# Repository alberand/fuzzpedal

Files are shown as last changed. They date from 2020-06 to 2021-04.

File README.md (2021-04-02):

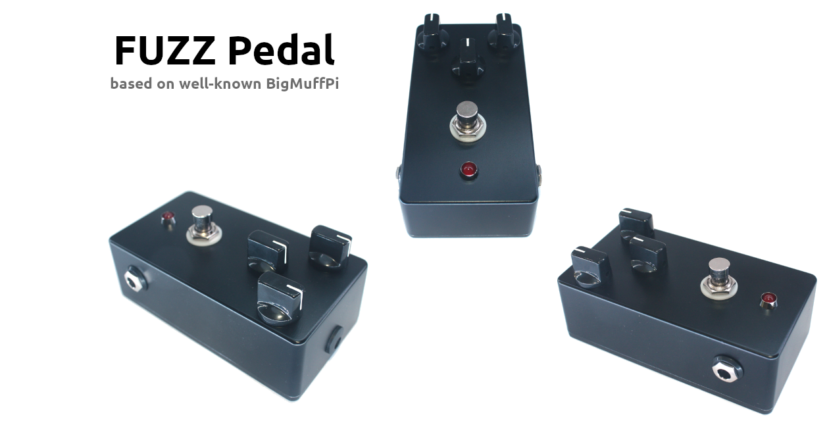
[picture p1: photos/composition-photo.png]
DIY Fuzz Pedal


This repository contains a lot of information on how to build a Fuzz Pedal based
on well-known Big Muff PI pedal.

## Demo Reconds

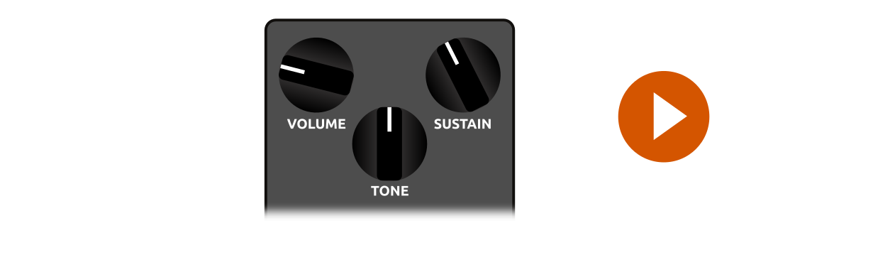
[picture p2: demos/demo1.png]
Demo 1
[][4] 

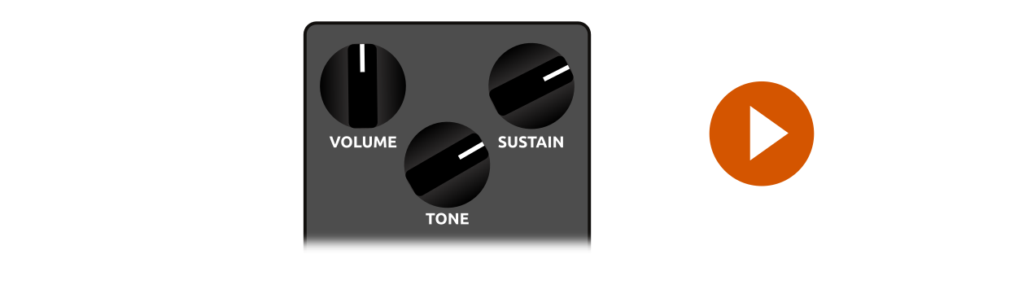
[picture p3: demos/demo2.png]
Demo 2
[][5] 

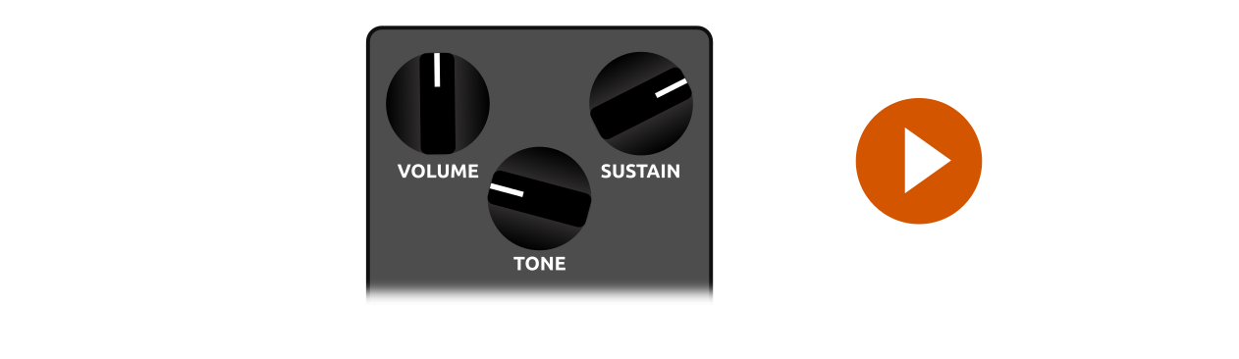
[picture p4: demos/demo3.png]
Demo 3
[][6] 

### Schematics

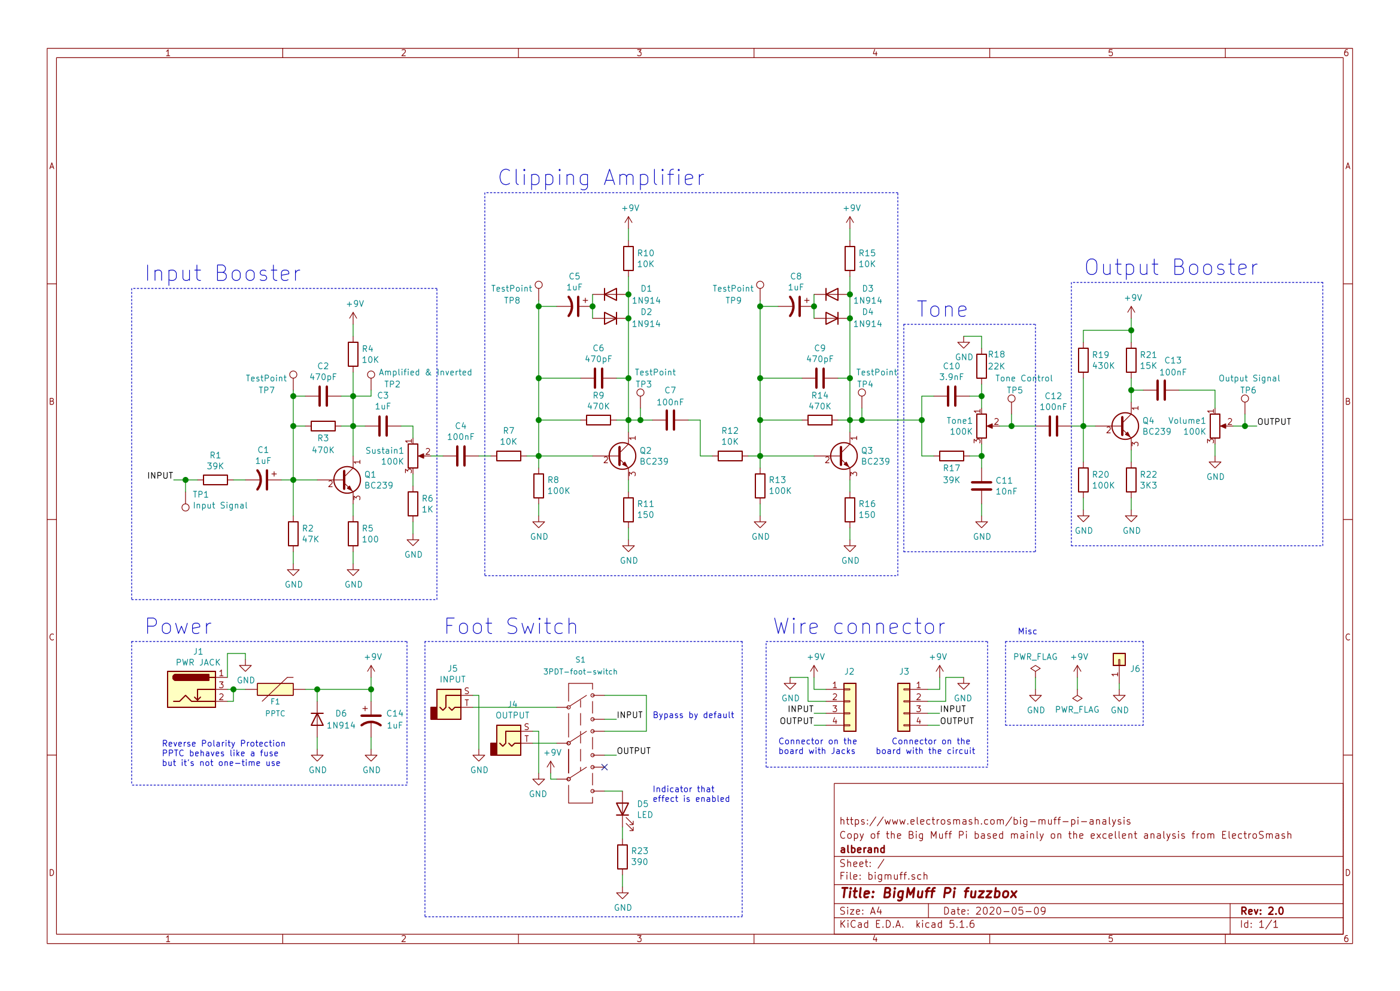
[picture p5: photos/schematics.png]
Fuzz Pedal schematics


### PCB dimensions

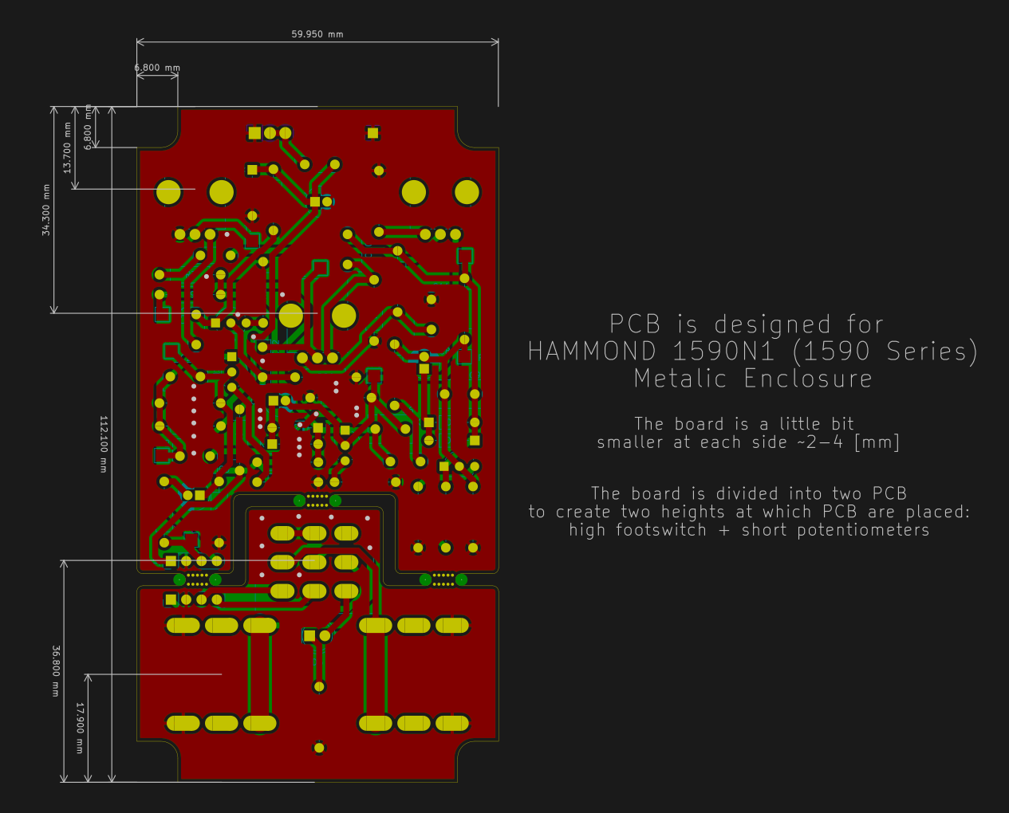
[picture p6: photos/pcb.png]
Fuzz Pedal PCB


### 3D Render of PCB

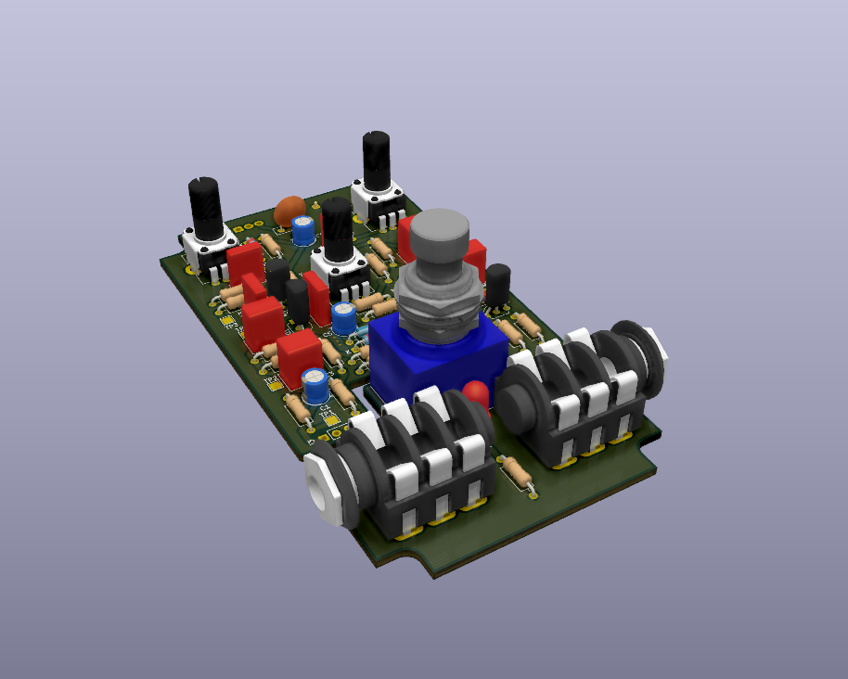
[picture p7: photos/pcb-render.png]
Fuzz Pedal render


### Photo of PCB

Photo of Fuzz Pedal PCB

### Photo of assembled pedal

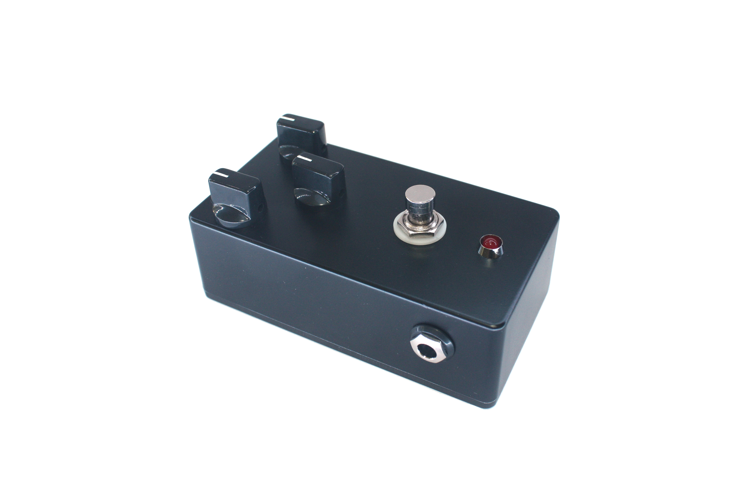
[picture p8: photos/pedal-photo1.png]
Photo of assembled Fuzz Pedal


## TODO

* Add [rubber feets][1] (After discussion seems to be unnecessary and it's better to have Hook-and-loop fastener)
* Write article on how to paint Aluminum case
* Add template for drilling holes (A4 paper with holes)
* Update BOM (better caps, better LED holder)  - in progress
* Try screen print on the case
* Describe screen printing process
* Find what to use as a final coat for case painting

## Cost

Here is crude cost calculation of one Pedal. Remember that this doesn't include
any tools. The shipping price could vary (in my case I had many more parcels
😕). In total one pedal cost about 50 - 60 💶 euro (without shipping) + you would
have a few paint sprays.

| Material Type | Quantity | Price [EUR] |
|---|---|---|
| PCB | 5 (min amount) | 8.5 |
| Electronic components & Misc | 1 set | 25 |
| Case | 1 | 11 |
| Ground & Color & Clear Paint | 3 | 6x3 |
| Shipping | ~4 | 20x4 |

How long does it take to make a pedal? If you have any experience in soldering,
painting it will take somewhere around 33 hours mainly due waiting for paint to
dry.

| Activity Type | Time [hours] |
|---|---|
| Board Soldering | 5 |
| Case drilling | 2 |
| Case cleaning & polishing | 0.5 |
| Case painting | 25 |
| Assembling | 0.5 |

## Assembling process

TODO In progress

The assebmly process is quite simple. The most time-consuming part is PCB
soldering. Otherwise, you just need to put PCB into box.

### Order components & PCB

1. Import BOM to Mouser or Farnell and order components. The BOM is prepared for
   those to distributors. However, sometimes components aren't in stock and it
   can take months for them to restock them.
2. Order the rest of the components from Aliexpress - enclosure and foot switch.
   Those parts are also available on Amazon. I would recommend to by foot switch
   from amazon as it seems to be in better quality. The case could be also
   ordered from Mouser or Farnell.
3. Import Gerber files to PCB manufacturer and order PCBs. I used jlcpcb.com
   which worked out quite well.

### Solder board

1. TODO image of the component placement (print it)
2. I recommend soldering components in the following order:
    1. Resistors
    2. Electrolytic Capacitors (those with polarity)
    3. Capacitor
    4. Transistors
    5. Diodes
    6. Thermal fuse (yellow)
    7. Potentiometers, Jacks and Switch
    8. Wires between PCBs
3. Prepare wires, LED with wires and power jack with wires
4. Solder wires to LED and to the Power jack, but don't solder it to the board
   yet. Also, don't forget to put heat shrink tubes.
5. Solder the LED to the board 

### Enclosure processing

TODO describe what instruments to use
1. Print the template for the hole placement (TODO not in the repo)
2. Cut the template and attach it to the case with adhesive tape
3. Drill the holes
4. Remove the template and polish the case with different sandpapers (TODO add
   sizes)
5. Paint the case (read the instruction on the spray):
    1. 2 layers of primer
    2. 2 layers of color paint
    3. 1 layers of protection layer
6. Screen printing (TODO)

### Assemble the pedal

1. Break the board
2. Put the LED into the case and screw it to the case
3. Screw switch and jacks
4. Put second board into the enclosure and screw the knobs
5. Put power jack into the enclosure
6. Solder power jack wires to the board
7. Use thermal glue (TODO it doesn't work) to fix the board inside the case
8. Screw the bottom of the enclosure

### References

* [ElectroSmash - Big Muff PI analysis](https://www.electrosmash.com/big-muff-pi-analysis)
* [How to "Screen printing"](https://www.youtube.com/watch?v=NS8Q9LUIKA8)

[1]: http://www.diyguitarpedals.com.au/shop/index.php?main_page=product_info&cPath=15&products_id=591
[2]: http://www.caravanelectroworks.com/?p=418
[3]: http://rezzonics.blogspot.com/2018/05/nutube-screamer-schematics-bom-layout.html
[4]: https://soundcloud.com/user-605705068/fuzzpedal-demo-param-1
[5]: https://soundcloud.com/user-605705068/fuzzpedal-demo-param-2
[6]: https://soundcloud.com/user-605705068/fuzzpedal-demo-param-3

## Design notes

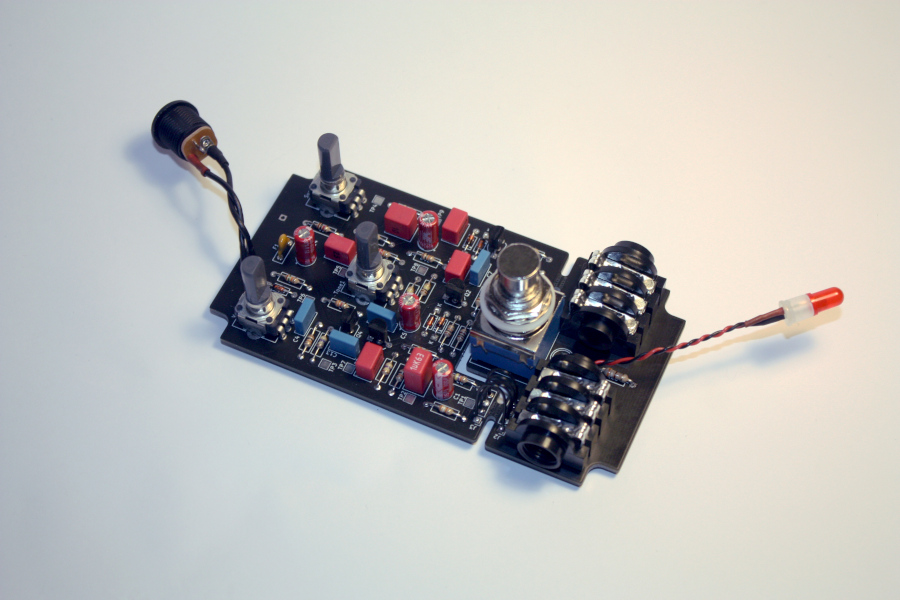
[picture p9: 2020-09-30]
photos/pcb-photo.jpg

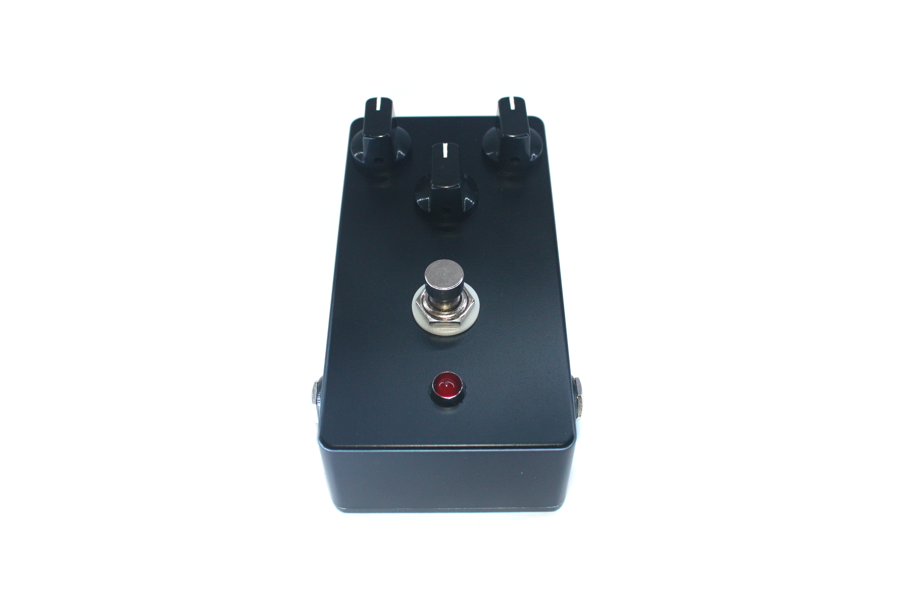
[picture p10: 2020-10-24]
photos/pedal-photo2.png

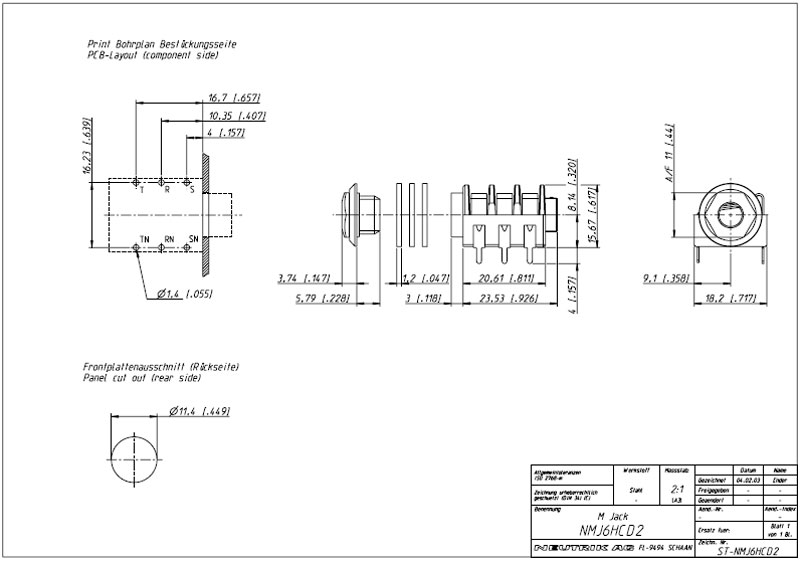
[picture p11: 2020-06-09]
datasheets/nmj6-size.jpg

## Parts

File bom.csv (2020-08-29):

Reference | Value | Footprint | Datasheet | Mfr. No | Mouser | Supplier | LCSC | Aliexpress | Comment | Field4
R1 | 39K | Resistor_THT:R_Axial_DIN0207_L6.3mm_D2.5mm_P10.16mm_Horizontal | https://cz.mouser.com/datasheet/2/447/yageo_yagos02873-1-1745585.pdf | CFR-12JB-52-39K | 603-CFR-12JB-52-39K | Mouser
C1 | 1uF | Capacitor_THT:CP_Radial_D5.0mm_P2.00mm | https://cz.mouser.com/datasheet/2/445/860020672005-1725471.pdf | 860020672005 | 710-860020672005 | Mouser
Q1 | BC239 | Package_TO_SOT_THT:TO-92L_Inline_Wide | https://cz.mouser.com/datasheet/2/308/BC550-D-1802078.pdf | BC549CTA | 512-BC549CTA | Mouser
R5 | 100 | Resistor_THT:R_Axial_DIN0207_L6.3mm_D2.5mm_P10.16mm_Horizontal | https://cz.mouser.com/datasheet/2/447/yageo_yagos02873-1-1745585.pdf | CFR-12JT-52-100R | 603-CFR-12JT-52-100R | Mouser
R2 | 47K | Resistor_THT:R_Axial_DIN0207_L6.3mm_D2.5mm_P10.16mm_Horizontal | https://cz.mouser.com/datasheet/2/447/yageo_yagos02873-1-1745585.pdf | CFR-12JB-52-47K | 603-CFR-12JB-52-47K | Mouser
R3 | 470K | Resistor_THT:R_Axial_DIN0207_L6.3mm_D2.5mm_P10.16mm_Horizontal | https://cz.mouser.com/datasheet/2/447/yageo_yagos02873-1-1745585.pdf | CFR-12JT-52-470K | 603-CFR-12JT-52-470K | Mouser
C2 | 470pF | Capacitor_THT:C_Rect_L7.2mm_W4.5mm_P5.00mm_FKS2_FKP2_MKS2_MKP2 | https://cz.mouser.com/datasheet/2/440/e_WIMA_FKP_2-1139852.pdf | FKP2D004701D00KSSD | 505-FKP2D004701DKSSD | Mouser
C3 | 1uF | Capacitor_THT:C_Rect_L7.2mm_W5.5mm_P5.00mm_FKS2_FKP2_MKS2_MKP2 | https://cz.mouser.com/datasheet/2/440/e_WIMA_MKS_2-1139871.pdf | MKS2C041001F00KI00 | 505-MKS2C041001FKI00 | Mouser
R4 | 10K | Resistor_THT:R_Axial_DIN0207_L6.3mm_D2.5mm_P10.16mm_Horizontal | https://cz.mouser.com/datasheet/2/447/yageo_yagos02873-1-1745585.pdf | CFR-12JT-52-10K | 603-CFR-12JT-52-10K | Mouser
R6 | 1K | Resistor_THT:R_Axial_DIN0207_L6.3mm_D2.5mm_P10.16mm_Horizontal | https://cz.mouser.com/datasheet/2/447/yageo_yagos02873-1-1745585.pdf | CFR-12JT-52-1K | 603-CFR-12JT-52-1K | Mouser
C4 | 100nF | Capacitor_THT:C_Rect_L7.2mm_W2.5mm_P5.00mm_FKS2_FKP2_MKS2_MKP2 | https://www.tdk-electronics.tdk.com/inf/20/20/db/fc_2009/B32520_529.pdf | B32529C104K000 | 871-B32529C104K000 | Mouser
R7 | 10K | Resistor_THT:R_Axial_DIN0207_L6.3mm_D2.5mm_P10.16mm_Horizontal | https://cz.mouser.com/datasheet/2/447/yageo_yagos02873-1-1745585.pdf | CFR-12JT-52-10K | 603-CFR-12JT-52-10K | Mouser
Q2 | BC239 | Package_TO_SOT_THT:TO-92L_Inline_Wide | https://cz.mouser.com/datasheet/2/308/BC550-D-1802078.pdf | BC549CTA | 512-BC549CTA | Mouser
R8 | 100K | Resistor_THT:R_Axial_DIN0207_L6.3mm_D2.5mm_P10.16mm_Horizontal | https://cz.mouser.com/datasheet/2/447/yageo_yagos02873-1-1745585.pdf | CFR-12JR-52-100K | 603-CFR-12JR-52-100K | Mouser
R9 | 470K | Resistor_THT:R_Axial_DIN0207_L6.3mm_D2.5mm_P10.16mm_Horizontal | https://cz.mouser.com/datasheet/2/447/yageo_yagos02873-1-1745585.pdf | CFR-12JT-52-470K | 603-CFR-12JT-52-470K | Mouser
C6 | 470pF | Capacitor_THT:C_Rect_L7.2mm_W4.5mm_P5.00mm_FKS2_FKP2_MKS2_MKP2 | https://cz.mouser.com/datasheet/2/440/e_WIMA_FKP_2-1139852.pdf | FKP2D004701D00KSSD | 505-FKP2D004701DKSSD | Mouser
C5 | 1uF | Capacitor_THT:CP_Radial_D5.0mm_P2.00mm | https://cz.mouser.com/datasheet/2/445/860020672005-1725471.pdf | 860020672005 | 710-860020672005 | Mouser
D1 | 1N914 | Diode_THT:D_DO-35_SOD27_P7.62mm_Horizontal | https://cz.mouser.com/datasheet/2/308/1N914-D-1801484.pdf | 1N914 | 512-1N914 | Mouser | C125665
D2 | 1N914 | Diode_THT:D_DO-35_SOD27_P7.62mm_Horizontal | https://cz.mouser.com/datasheet/2/308/1N914-D-1801484.pdf | 1N914 | 512-1N914 | Mouser | C125665
R10 | 10K | Resistor_THT:R_Axial_DIN0207_L6.3mm_D2.5mm_P10.16mm_Horizontal | https://cz.mouser.com/datasheet/2/447/yageo_yagos02873-1-1745585.pdf | CFR-12JT-52-10K | 603-CFR-12JT-52-10K | Mouser
R11 | 150 | Resistor_THT:R_Axial_DIN0207_L6.3mm_D2.5mm_P10.16mm_Horizontal | https://cz.mouser.com/datasheet/2/447/yageo_yagos02873-1-1745585.pdf | CFR-12JT-52-150R | 603-CFR-12JT-52-150R | Mouser
C7 | 100nF | Capacitor_THT:C_Rect_L7.2mm_W2.5mm_P5.00mm_FKS2_FKP2_MKS2_MKP2 | https://www.tdk-electronics.tdk.com/inf/20/20/db/fc_2009/B32520_529.pdf | B32529C104K000 | 871-B32529C104K000 | Mouser
R12 | 10K | Resistor_THT:R_Axial_DIN0207_L6.3mm_D2.5mm_P10.16mm_Horizontal | https://cz.mouser.com/datasheet/2/447/yageo_yagos02873-1-1745585.pdf | CFR-12JT-52-10K | 603-CFR-12JT-52-10K | Mouser
R13 | 100K | Resistor_THT:R_Axial_DIN0207_L6.3mm_D2.5mm_P10.16mm_Horizontal | https://cz.mouser.com/datasheet/2/447/yageo_yagos02873-1-1745585.pdf | CFR-12JR-52-100K | 603-CFR-12JR-52-100K | Mouser
R14 | 470K | Resistor_THT:R_Axial_DIN0207_L6.3mm_D2.5mm_P10.16mm_Horizontal | https://cz.mouser.com/datasheet/2/447/yageo_yagos02873-1-1745585.pdf | CFR-12JT-52-470K | 603-CFR-12JT-52-470K | Mouser
C9 | 470pF | Capacitor_THT:C_Rect_L7.2mm_W4.5mm_P5.00mm_FKS2_FKP2_MKS2_MKP2 | https://cz.mouser.com/datasheet/2/440/e_WIMA_FKP_2-1139852.pdf | FKP2D004701D00KSSD | 505-FKP2D004701DKSSD | Mouser
C8 | 1uF | Capacitor_THT:CP_Radial_D5.0mm_P2.00mm | https://cz.mouser.com/datasheet/2/445/860020672005-1725471.pdf | 860020672005 | 710-860020672005 | Mouser
D3 | 1N914 | Diode_THT:D_DO-35_SOD27_P7.62mm_Horizontal | https://cz.mouser.com/datasheet/2/308/1N914-D-1801484.pdf | 1N914 | 512-1N914 | Mouser | C125665
D4 | 1N914 | Diode_THT:D_DO-35_SOD27_P7.62mm_Horizontal | https://cz.mouser.com/datasheet/2/308/1N914-D-1801484.pdf | 1N914 | 512-1N914 | Mouser | C125665
R15 | 10K | Resistor_THT:R_Axial_DIN0207_L6.3mm_D2.5mm_P10.16mm_Horizontal | https://cz.mouser.com/datasheet/2/447/yageo_yagos02873-1-1745585.pdf | CFR-12JT-52-10K | 603-CFR-12JT-52-10K | Mouser
R16 | 150 | Resistor_THT:R_Axial_DIN0207_L6.3mm_D2.5mm_P10.16mm_Horizontal | https://cz.mouser.com/datasheet/2/447/yageo_yagos02873-1-1745585.pdf | CFR-12JT-52-150R | 603-CFR-12JT-52-150R | Mouser
Tone1 | 100K | Potentiometer_THT:Potentiometer_Alps_RK09K_Single_Vertical | https://cz.mouser.com/datasheet/2/15/RK09K-771158.pdf | RK09D113BF25B15 | 688-RK09D113BF25B15 | Mouser
C10 | 3.9nF | Capacitor_THT:C_Rect_L7.2mm_W4.5mm_P5.00mm_FKS2_FKP2_MKS2_MKP2 | https://cz.mouser.com/datasheet/2/440/e_WIMA_FKP_2-1139852.pdf | FKP2C013901D00HC00 | 505-FKP2C013901DHC00 | Mouser
R17 | 39K | Resistor_THT:R_Axial_DIN0207_L6.3mm_D2.5mm_P10.16mm_Horizontal | https://cz.mouser.com/datasheet/2/447/yageo_yagos02873-1-1745585.pdf | CFR-12JB-52-39K | 603-CFR-12JB-52-39K | Mouser
R18 | 22K | Resistor_THT:R_Axial_DIN0207_L6.3mm_D2.5mm_P10.16mm_Horizontal | https://cz.mouser.com/datasheet/2/447/yageo_yagos02873-1-1745585.pdf | CFR-12JT-52-22K | 603-CFR-12JT-52-22K | Mouser
C12 | 100nF | Capacitor_THT:C_Rect_L7.2mm_W2.5mm_P5.00mm_FKS2_FKP2_MKS2_MKP2 | https://www.tdk-electronics.tdk.com/inf/20/20/db/fc_2009/B32520_529.pdf | B32529C104K000 | 871-B32529C104K000 | Mouser
Q4 | BC239 | Package_TO_SOT_THT:TO-92L_Inline_Wide | https://cz.mouser.com/datasheet/2/308/BC550-D-1802078.pdf | BC549CTA | 512-BC549CTA | Mouser
R21 | 15K | Resistor_THT:R_Axial_DIN0207_L6.3mm_D2.5mm_P10.16mm_Horizontal | https://cz.mouser.com/datasheet/2/447/yageo_yagos02873-1-1745585.pdf | CFR-12JT-52-15K | 603-CFR-12JT-52-15K | Mouser
R19 | 430K | Resistor_THT:R_Axial_DIN0207_L6.3mm_D2.5mm_P10.16mm_Horizontal | https://cz.mouser.com/datasheet/2/447/yageo_yagos02873-1-1745585.pdf | CFR-12JB-52-430K | 603-CFR-12JB-52-430K | Mouser
C13 | 100nF | Capacitor_THT:C_Rect_L7.2mm_W2.5mm_P5.00mm_FKS2_FKP2_MKS2_MKP2 | https://www.tdk-electronics.tdk.com/inf/20/20/db/fc_2009/B32520_529.pdf | B32529C104K000 | 871-B32529C104K000 | Mouser
Volume1 | 100K | Potentiometer_THT:Potentiometer_Alps_RK09K_Single_Vertical | https://cz.mouser.com/datasheet/2/15/RK09K-771158.pdf | RK09D113BF25B15 | 688-RK09D113BF25B15 | Mouser
Sustain1 | 100K | Potentiometer_THT:Potentiometer_Alps_RK09K_Single_Vertical | https://cz.mouser.com/datasheet/2/15/RK09K-771158.pdf | RK09D113BF25B15 | 688-RK09D113BF25B15 | Mouser
R20 | 100K | Resistor_THT:R_Axial_DIN0207_L6.3mm_D2.5mm_P10.16mm_Horizontal | https://cz.mouser.com/datasheet/2/447/yageo_yagos02873-1-1745585.pdf | CFR-12JR-52-100K | 603-CFR-12JR-52-100K | Mouser
R22 | 3K3 | Resistor_THT:R_Axial_DIN0207_L6.3mm_D2.5mm_P10.16mm_Horizontal | https://cz.mouser.com/datasheet/2/447/yageo_yagos02873-1-1745585.pdf | CFR-12JR-52-3K3 | 603-CFR-12JR-52-3K3 | Mouser
C11 | 10nF | Capacitor_THT:C_Rect_L7.2mm_W5.5mm_P5.00mm_FKS2_FKP2_MKS2_MKP2 | https://cz.mouser.com/datasheet/2/440/e_WIMA_FKP_2-1139852.pdf | FKP2C021001G00KSSD | 505-FKP2C021001G00KS | Mouser
Q3 | BC239 | Package_TO_SOT_THT:TO-92L_Inline_Wide | https://cz.mouser.com/datasheet/2/308/BC550-D-1802078.pdf | BC549CTA | 512-BC549CTA | Mouser
S1 | 3PDT-foot-switch | bigmuffpi:SF17020F-0302-21R-L | https://cz.mouser.com/datasheet/2/13/SF17_SF12030F-1155740.pdf | 3PDT 9-Pin | 107-SF17020F-32-21RL | Aliexpress |  | https://www.aliexpress.com/item/1761081145.html?spm=a2g0o.cart.0.0.9a9e3c00NMRYVw&mp=1 | Much much cheaper from Aliexpress (look for 3PDT) | SWCH-10554
J1 | PWR JACK | Connector_PinHeader_2.54mm:PinHeader_1x03_P2.54mm_Vertical | https://www.aliexpress.com/wholesale?catId=0&SearchText=panel+mount+barrel+jack |  |  | Aliexpress
D6 | 1N914 | Diode_THT:D_DO-35_SOD27_P7.62mm_Horizontal | https://cz.mouser.com/datasheet/2/308/1N914-D-1801484.pdf | 1N914 | 512-1N914 | Mouser | C125665
J5 | INPUT | bigmuffpi:NMJ6HC-S | https://www.neutrik.us/en-us/product/nmj4hc-s.pdf | NMJ4HC-S | 568-NMJ4HC-S | Mouser
J4 | OUTPUT | bigmuffpi:NMJ6HC-S | https://www.neutrik.us/en-us/product/nmj4hc-s.pdf | NMJ4HC-S | 568-NMJ4HC-S | Mouser
R23 | 390 | Resistor_THT:R_Axial_DIN0207_L6.3mm_D2.5mm_P10.16mm_Horizontal | https://cz.mouser.com/datasheet/2/447/yageo_yagos02873-1-1745585.pdf | CFR-12JB-52-390R | 603-CFR-12JB-52-390R | Mouser
D5 | LED | LED_THT:LED_D5.0mm | https://cz.mouser.com/datasheet/2/427/tlhg540-1766965.pdf | TLHR5400-AS12Z | 78-TLHR5400-AS12Z | Mouser | C162069
F1 | PPTC | Capacitor_THT:C_Disc_D8.0mm_W2.5mm_P5.00mm | https://cz.mouser.com/datasheet/2/54/mfr-777680.pdf | MF-R020 | 652-MF-R020 | Mouser |  |  |  | RES-08585
C14 | 1uF | Capacitor_THT:CP_Radial_D5.0mm_P2.00mm | https://cz.mouser.com/datasheet/2/445/860020672005-1725471.pdf | 860020672005 | 710-860020672005 | Mouser

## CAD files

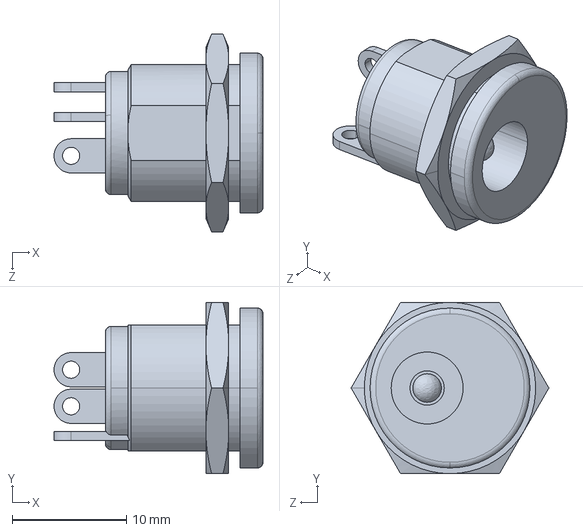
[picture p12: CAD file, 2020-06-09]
fuzzpedal/3dmodels/KLS1-DC-022B.step
18.3 x 15.0 x 17.3 mm

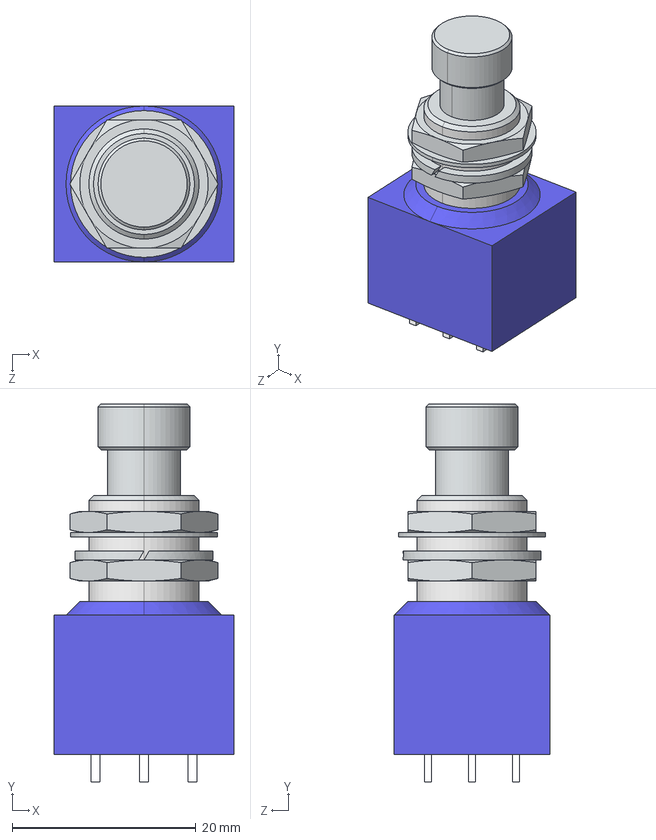
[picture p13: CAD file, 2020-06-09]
fuzzpedal/3dmodels/Footswich_3PDT.step
19.6 x 41.2 x 17.0 mm

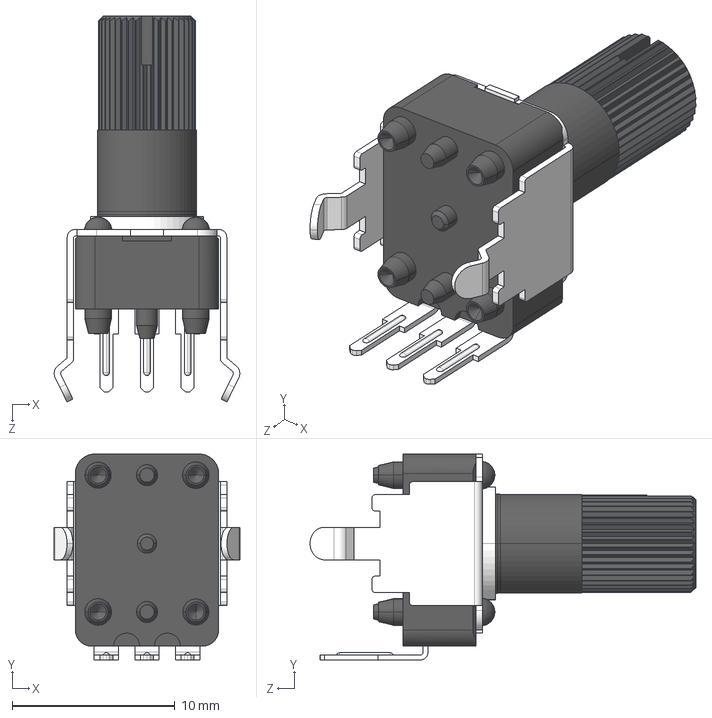
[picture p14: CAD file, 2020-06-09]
fuzzpedal/3dmodels/RK09K1130-20-1.step
11.4 x 12.7 x 23.7 mm

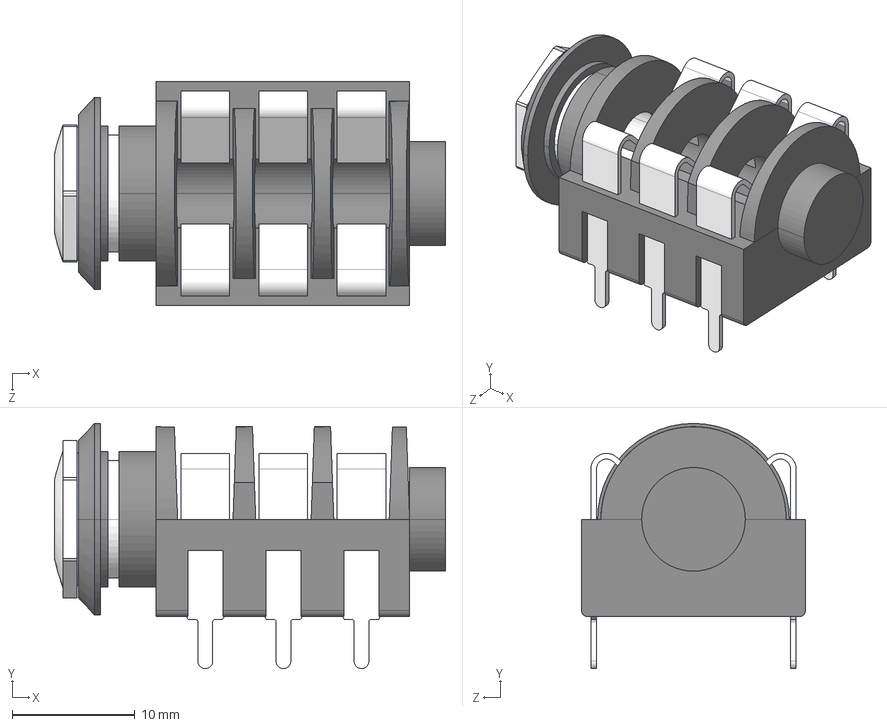
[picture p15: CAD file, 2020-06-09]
fuzzpedal/3dmodels/NMJ4HC-S.step
31.8 x 19.9 x 18.2 mm
SW3dPS-NMJ6HCD2_Imported5
SW3dPS-NMJ6HCD2_Imported4

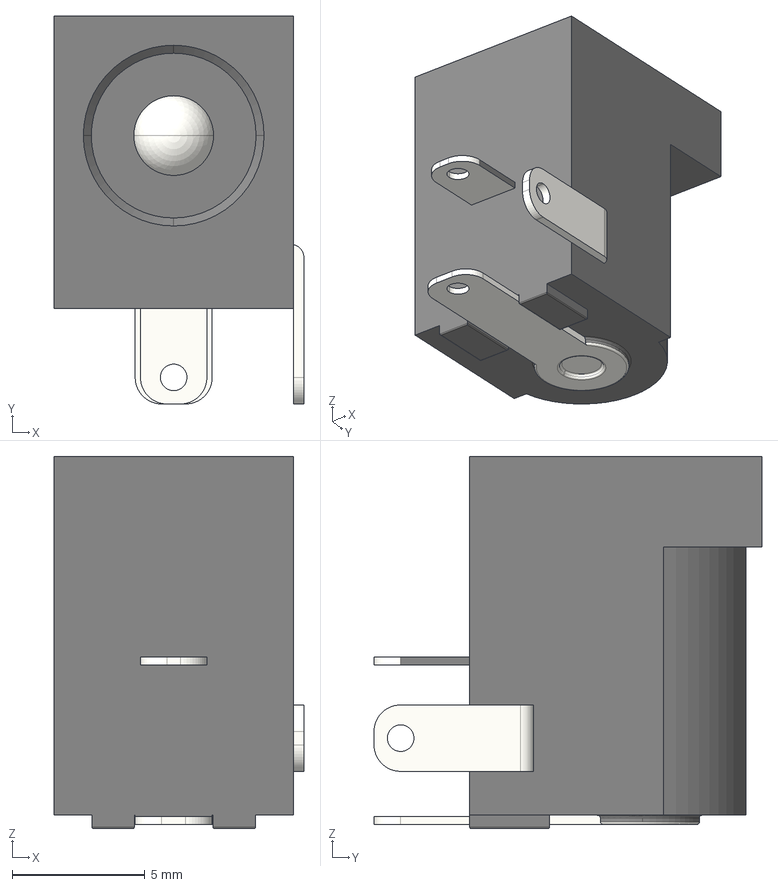
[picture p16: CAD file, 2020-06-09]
fuzzpedal/3dmodels/dc-005-5a-2_0.step
9.40 x 14.6 x 14.0 mm

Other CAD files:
fuzzpedal/3dmodels/ALPS_RK09K113_Potentiometer.skp

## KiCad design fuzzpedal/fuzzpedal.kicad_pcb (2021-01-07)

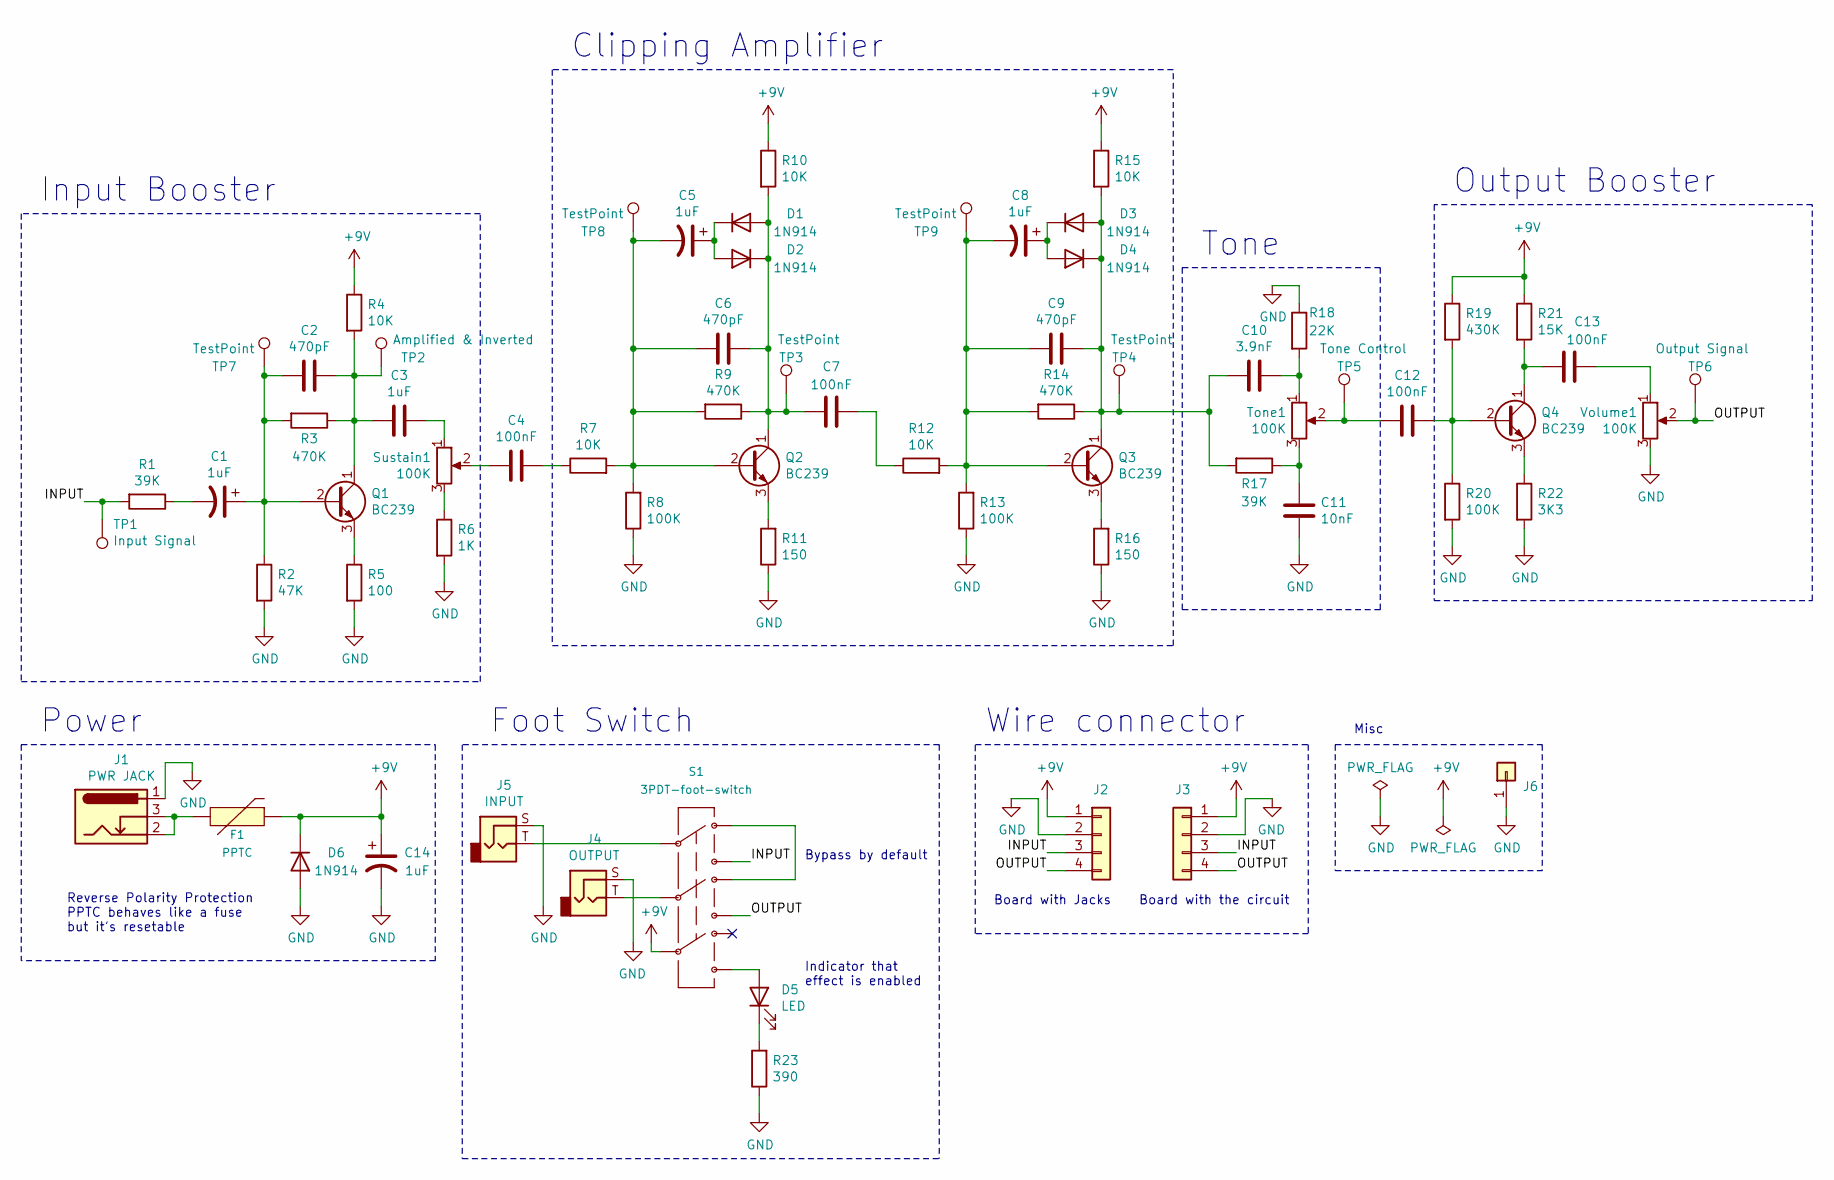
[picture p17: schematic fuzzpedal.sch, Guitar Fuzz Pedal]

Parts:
C1, C5, C8, C14: 1uF; CP_Radial_D5.0mm_P2.00mm; Mouser 710-860020672005
C2, C6, C9: 470pF; C_Rect_L7.2mm_W4.5mm_P5.00mm_FKS2_FKP2_MKS2_MKP2; Mouser 505-FKP2D004701DKSSD
C3: 1uF; C_Rect_L7.2mm_W5.5mm_P5.00mm_FKS2_FKP2_MKS2_MKP2; Mouser 505-MKS2C041001FKI00
C4, C7, C12, C13: 100nF; C_Rect_L7.2mm_W2.5mm_P5.00mm_FKS2_FKP2_MKS2_MKP2; Mouser 871-B32529C104K000
C10: 3.9nF; C_Rect_L7.2mm_W4.5mm_P5.00mm_FKS2_FKP2_MKS2_MKP2; Mouser 505-FKP2C013901DHC00
C11: 10nF; C_Rect_L7.2mm_W5.5mm_P5.00mm_FKS2_FKP2_MKS2_MKP2; Mouser 505-FKP2C021001G00KS
D1, D2, D3, D4, D6: 1N914; D_DO-35_SOD27_P7.62mm_Horizontal; LCSC C125665
D5: LED; LED_D5.0mm; LCSC C162069
F1: PPTC; C_Disc_D8.0mm_W2.5mm_P5.00mm; Mouser 652-MF-R020
J1: PWR JACK; PinHeader_1x03_P2.54mm_Vertical
J2: Wire connector (smol); PinHeader_1x04_P2.54mm_Vertical
J3: Wire connector (circuit); PinHeader_1x04_P2.54mm_Vertical
J4: OUTPUT; NMJ6HC-S; Mouser 568-NMJ4HC-S
J5: INPUT; NMJ6HC-S; Mouser 568-NMJ4HC-S
J6: GND for scope; PinHeader_1x01_P2.54mm_Vertical
Q1, Q2, Q3, Q4: BC239; TO-92L_Inline_Wide; Mouser 512-BC549CTA
R1, R17: 39K; R_Axial_DIN0207_L6.3mm_D2.5mm_P10.16mm_Horizontal; Mouser 603-CFR-12JB-52-39K
R2: 47K; R_Axial_DIN0207_L6.3mm_D2.5mm_P10.16mm_Horizontal; Mouser 603-CFR-12JB-52-47K
R3, R9, R14: 470K; R_Axial_DIN0207_L6.3mm_D2.5mm_P10.16mm_Horizontal; Mouser 603-CFR-12JT-52-470K
R4, R7, R10, R12, R15: 10K; R_Axial_DIN0207_L6.3mm_D2.5mm_P10.16mm_Horizontal; Mouser 603-CFR-12JT-52-10K
R5: 100; R_Axial_DIN0207_L6.3mm_D2.5mm_P10.16mm_Horizontal; Mouser 603-CFR-12JT-52-100R
R6: 1K; R_Axial_DIN0207_L6.3mm_D2.5mm_P10.16mm_Horizontal; Mouser 603-CFR-12JT-52-1K
R8, R13, R20: 100K; R_Axial_DIN0207_L6.3mm_D2.5mm_P10.16mm_Horizontal; Mouser 603-CFR-12JR-52-100K
R11, R16: 150; R_Axial_DIN0207_L6.3mm_D2.5mm_P10.16mm_Horizontal; Mouser 603-CFR-12JT-52-150R
R18: 22K; R_Axial_DIN0207_L6.3mm_D2.5mm_P10.16mm_Horizontal; Mouser 603-CFR-12JT-52-22K
R19: 430K; R_Axial_DIN0207_L6.3mm_D2.5mm_P10.16mm_Horizontal; Mouser 603-CFR-12JB-52-430K
R21: 15K; R_Axial_DIN0207_L6.3mm_D2.5mm_P10.16mm_Horizontal; Mouser 603-CFR-12JT-52-15K
R22: 3K3; R_Axial_DIN0207_L6.3mm_D2.5mm_P10.16mm_Horizontal; Mouser 603-CFR-12JR-52-3K3
R23: 390; R_Axial_DIN0207_L6.3mm_D2.5mm_P10.16mm_Horizontal; Mouser 603-CFR-12JB-52-390R
S1: 3PDT-foot-switch; SF17020F-0302-21R-L; Mouser 107-SF17020F-32-21RL
Sustain1: 100K; Potentiometer_Alps_RK09K_Single_Vertical; Mouser 688-RK09D113BF25B15
TP1: Input Signal; TestPoint_Pad_2.0x2.0mm
TP2: Amplified & Inverted; TestPoint_Pad_2.0x2.0mm
TP3, TP4, TP7, TP8, TP9: TestPoint; TestPoint_Pad_2.0x2.0mm
TP5: Tone Control; TestPoint_Pad_2.0x2.0mm
TP6: Output Signal; TestPoint_Pad_2.0x2.0mm
Tone1: 100K; Potentiometer_Alps_RK09K_Single_Vertical; Mouser 688-RK09D113BF25B15
Volume1: 100K; Potentiometer_Alps_RK09K_Single_Vertical; Mouser 688-RK09D113BF25B15

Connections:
+9V: C14.1, D6.1 (K), F1.2, J2.1, J3.1, R4.1, R10.1, R15.1, R19.1, R21.1, S1.8
/INPUT: J2.3, J3.3, R1.2, S1.3, TP1.1
/OUTPUT: J2.4, J3.4, S1.6, TP6.1, Volume1.2
GND: C11.2, C14.2, D6.2 (A), J1.1, J2.2, J3.2, J4.S, J5.S, J6.1, R2.2, R5.2, R6.2, R8.1, R11.1, R13.1, R16.1, R18.1, R20.2, R22.2, R23.1, Volume1.3; also elsewhere on the board
unnamed: C1.1, C2.2, Q1.2 (B), R2.1, R3.2, TP7.1
unnamed: C1.2, R1.1
unnamed: C2.1, C3.2, Q1.1 (C), R3.1, R4.2, TP2.1
unnamed: C3.1, Sustain1.1
unnamed: C4.1, R7.1
unnamed: C4.2, Sustain1.2
unnamed: C5.1, D1.1 (K), D2.2 (A)
unnamed: C5.2, C6.2, Q2.2 (B), R7.2, R8.2, R9.2, TP8.1
unnamed: C6.1, C7.2, D1.2 (A), D2.1 (K), Q2.1 (C), R9.1, R10.2, TP3.1
unnamed: C7.1, R12.1
unnamed: C8.1, D3.1 (K), D4.2 (A)
unnamed: C8.2, C9.2, Q3.2 (B), R12.2, R13.2, R14.2, TP9.1
unnamed: C10.1, R18.2, Tone1.1
unnamed: C9.1, C10.2, D3.2 (A), D4.1 (K), Q3.1 (C), R14.1, R15.2, R17.2, TP4.1
unnamed: C11.1, R17.1, Tone1.3
unnamed: C12.1, Q4.2 (B), R19.2, R20.1
unnamed: C12.2, TP5.1, Tone1.2
unnamed: C13.1, Volume1.1
unnamed: C13.2, Q4.1 (C), R21.2
unnamed: D5.1 (K), R23.2
unnamed: D5.2 (A), S1.9
unnamed: F1.1, J1.2, J1.3
unnamed 26: J4.T, S1.5; also elsewhere on the board
unnamed 27: J5.T, S1.2; also elsewhere on the board
unnamed: Q1.3 (E), R5.1
unnamed: Q2.3 (E), R11.2
unnamed: Q3.3 (E), R16.2
unnamed: Q4.3 (E), R22.1
unnamed: R6.1, Sustain1.3
unnamed: S1.1, S1.4

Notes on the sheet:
Input Booster
Clipping Amplifier
Tone
Output Booster
Bypass by default
Foot Switch
Power
Indicator that effect is enabled
Misc
Reverse Polarity Protection PPTC behaves like a fuse but it's resetable
Board with the circuit
Board with Jacks
Wire connector

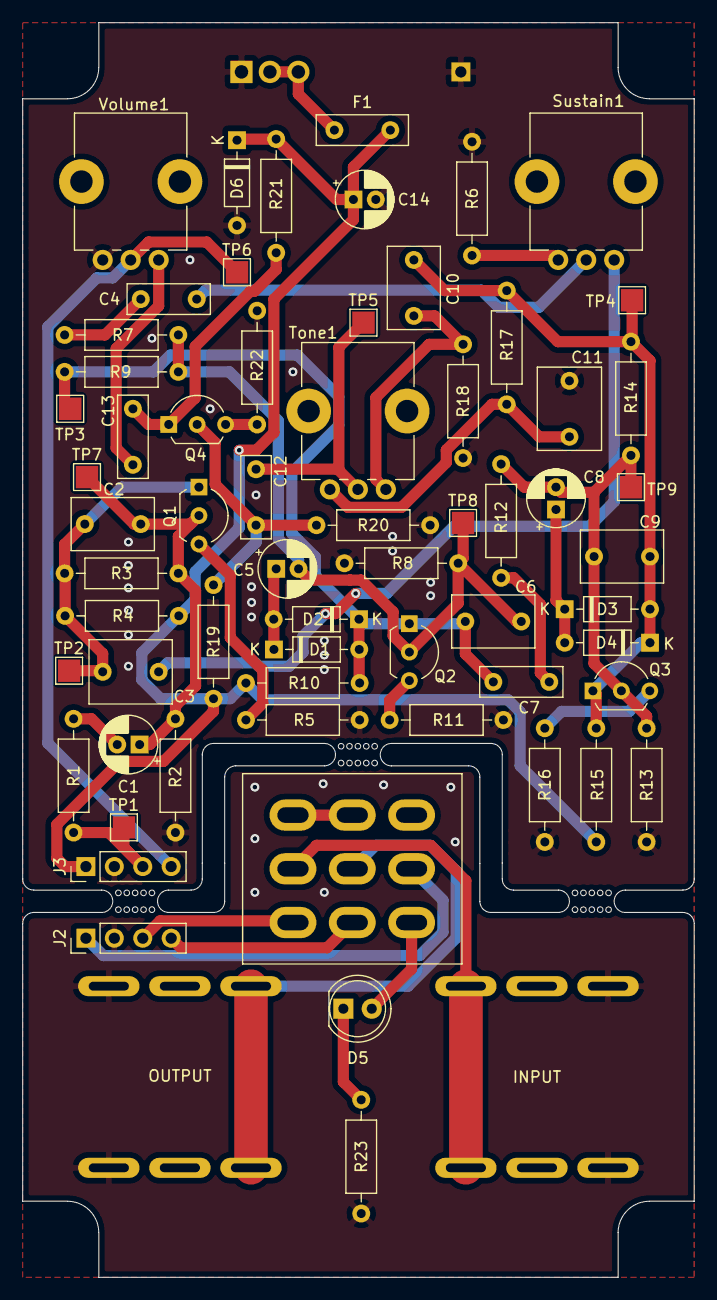
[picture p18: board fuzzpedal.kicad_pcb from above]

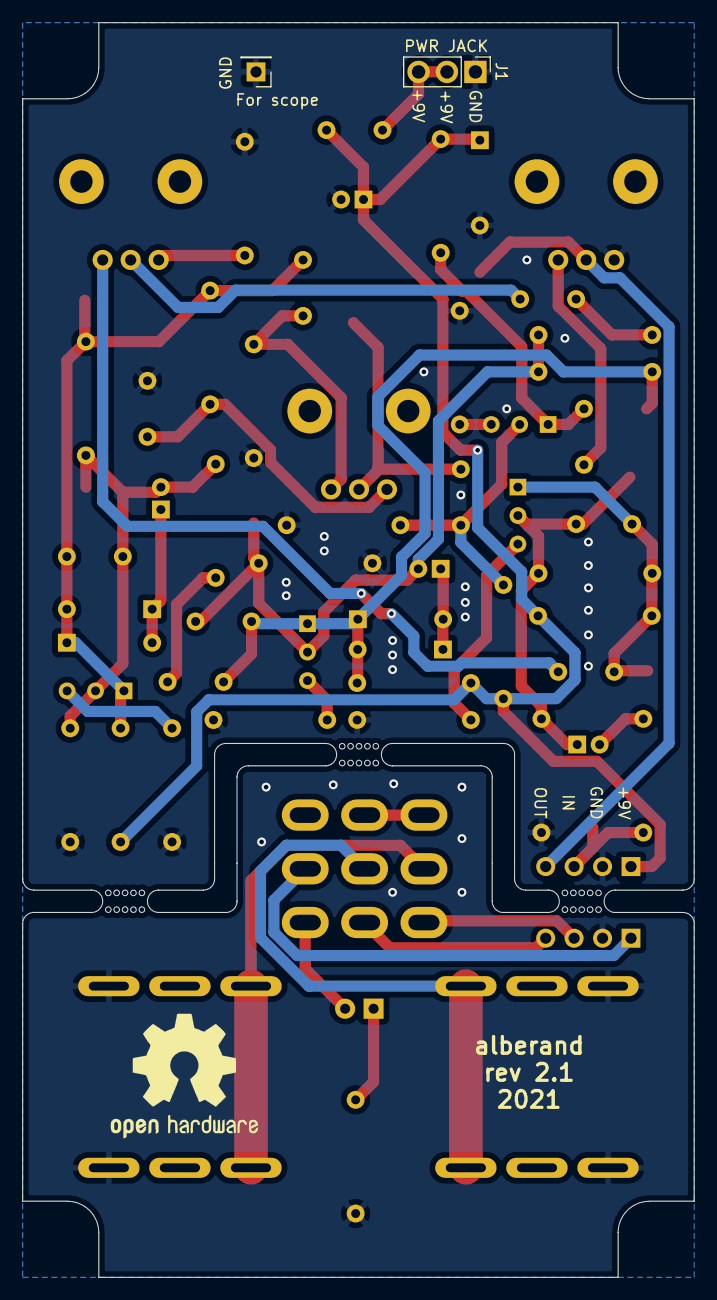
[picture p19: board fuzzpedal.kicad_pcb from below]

Board: 2 copper layers, 60.0 x 112.1 mm, 70 parts (2 on the bottom side), 34 nets.

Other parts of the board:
INPUT: INPUT; NMJ6HC-S
Je: GND for scope; PinHeader_1x01_P2.54mm_Vertical
OUTPUT: OUTPUT; NMJ6HC-S
mouse-bite-2mm-slot, mouse-bite-2mm-slot#2, mouse-bite-2mm-slot#3: VAL**; mouse-bite-2mm-slot

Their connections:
GND: INPUT.S, Je.1, OUTPUT.S; also elsewhere on the board
unnamed 26: OUTPUT.T; also elsewhere on the board
unnamed 27: INPUT.T; also elsewhere on the board

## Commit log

2020-05-09 add: initial schematics
    [bigmuff.kicad_pcb, bigmuff.sch]
2020-05-10 add: not connected to switch
    [bigmuff.sch]
2020-05-10 add: assign big bunch of components
    [bigmuff.sch]
2020-05-22 fix: audio IN/OUT change to 4 pin jacks
    [bigmuff.sch]
2020-05-22 add: footprints for 100SP switch and 3PDT foot switch
2020-06-09 add: 3D models for component
    [ALPS_RK09K113_Potentiometer.skp, Footswich_3PDT.step, KLS1-DC-022B.step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]
2020-06-09 add: footprint for NMJ6HC-S
2020-06-09 add: mostly hw layout
    [bigmuff.sch]
2020-06-09 add: dir for mechanics
    [1590B.stp]
2020-06-09 fix: more changes to the layout
    [bigmuff.kicad_pcb]
2020-06-10 fix: update capacitors to the Film one
    [bigmuff.sch]
2020-06-11 fix: re-layout board for a new film capacitors
    [bigmuff.kicad_pcb]
2020-06-11 fix: 3D models of capacitors and wire buses
    [bigmuff.kicad_pcb]
2020-06-20 add: layout changes
    [bigmuff.kicad_pcb]
2020-06-20 fix: LED indicates effect
    [bigmuff.sch]
2020-06-20 fix: new LED position on the board
    As now LED is used to indicate enabled effect it should be located near the foot switch
    [bigmuff.kicad_pcb]
2020-06-20 fix: remove 3D models from pin headers
    [bigmuff.kicad_pcb]
2020-06-20 fix: silk screen
    [bigmuff.kicad_pcb]
2020-06-22 fix: LED shows when effect is on
    [bigmuff.sch]
2020-06-22 refactor: remove old BOM
2020-06-22 add: slight changes in bom
2020-06-22 fix: wrong input resistor
    [bigmuff.sch]
2020-06-22 fix: reroute board for LED
    [bigmuff.kicad_pcb]
2020-06-23 add: OSHW and sing silkscreen
    [bigmuff.kicad_pcb]
2020-06-23 fix: some minor silkscreen
    [bigmuff.kicad_pcb]
2020-06-24 add: gerbers for rev 1.0
    [bigmuff-B_Cu.gbr, bigmuff-B_Mask.gbr, bigmuff-B_SilkS.gbr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]
2020-06-24 add: gerber output directory
    [bigmuff.kicad_pcb]
2020-06-24 fix: wrong resistor value
2020-06-24 add: BOM for rev 1.0
    [bom.csv]
2020-06-24 fix: cut off schematics image
2020-06-24 fix: rename and enlarge PCB render image
2020-06-24 fix: change resistor model
    On the previous one min. order is 5000 pieces
    [bigmuff.sch, bom.csv]
2020-06-25 fix: too small spacing (3 mm min)
    [bigmuff.kicad_pcb]
2020-06-25 add: new gerbers with bigger spacing
    [bigmuff-B_Cu.gbr, bigmuff-B_Mask.gbr, bigmuff-B_SilkS.gbr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]
2020-07-24 fix: adjust size of the board to 1590N1
    [bigmuff.kicad_pcb]
2020-07-24 add: dimension notation on PCB
    [bigmuff.kicad_pcb]
2020-07-24 add: PCB images
2020-07-24 fix: update schematics
2020-08-12 add: redo board cut off for new board
    [bigmuff.kicad_pcb]
2020-08-12 add: PCB 3d model
2020-08-12 fix: wide footprint for transistors
    [bigmuff.sch]
2020-08-13 add: reverse polarity protection based on PPTC
    [bigmuff.sch]
2020-08-13 add: more testpoints
    [bigmuff.sch]
2020-08-13 fix: change revision number to two
    [bigmuff.sch]
2020-08-13 add: assign footprint to PPTC
    [bigmuff.sch]
2020-08-13 fix: minor name fix for PPTC
    [bigmuff.sch]
2020-08-13 add: pick PPTC component on mouser
    [bigmuff.sch]
2020-08-13 fix: wider pads for 3PDT foot switch
2020-08-14 add: decoupling transistor
    [bigmuff.sch]
2020-08-14 add: update netlist to rev 2.0
    [bigmuff.kicad_pcb]
2020-08-14 fix: switch input and output jacks
    [bigmuff.kicad_pcb]
2020-08-14 refactor: remove tracks, mouse bites, fab text
    [bigmuff.kicad_pcb]
2020-08-14 add: GND pin for scope
    [bigmuff.kicad_pcb]
2020-08-14 add: note about enclosure painting
2020-08-14 add: skeleton of the assembling manual
2020-08-14 fix: transistor pin mapping
    [bigmuff.sch]
2020-08-25 add: wire connectors on schematics
    [bigmuff.sch]
2020-08-25 add: layout testpoints
    [bigmuff.kicad_pcb]
2020-08-25 fix: wrong footprint for connectors
    [bigmuff.sch]
2020-08-28 add: first version of new layout
    [bigmuff.kicad_pcb]
2020-08-29 fix: update footprints on the board
    [bigmuff.kicad_pcb]
2020-08-29 add: link to video about screen printing
2020-08-29 fix: assign 3D models to footprints
    [bigmuff.kicad_pcb]
2020-08-29 add: dimensions + minor fixes
    [bigmuff.kicad_pcb]
2020-08-29 add: reason why board is divided into two
    [bigmuff.kicad_pcb]
2020-08-29 fix: one of the dimensions
    [bigmuff.kicad_pcb]
2020-08-29 fix: bigger pads for barell jack
    [bigmuff.kicad_pcb]
2020-08-29 fix: minor fixes of vias and page settings
    [bigmuff.kicad_pcb]
2020-08-29 add: new gerbers
    [bigmuff-B_Cu.gbr, bigmuff-B_Mask.gbr, bigmuff-B_SilkS.gbr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]
2020-08-29 fix: minor fixes
    [bigmuff.kicad_pcb]
2020-08-29 refactor: remove pin header 3D model
    [bigmuff.kicad_pcb]
2020-08-29 add: new BOM
    [bom.csv]
2020-09-09 fix: silkscreen with rev2.0
    [bigmuff.kicad_pcb]
2020-09-09 refactor: changed notes
    [bigmuff.sch]
2020-09-18 add: the latest gerbers for v2.0
    [bigmuff-B_Cu.gbr, bigmuff-B_Mask.gbr, bigmuff-B_SilkS.gbr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]
2020-09-30 add: Interactive BOM
2020-09-30 add: photo of PCB
2020-10-24 add: photos of assembled pedal
2020-10-28 refactor: rename hardware dir
    [ALPS_RK09K113_Potentiometer.skp, Footswich_3PDT.step, KLS1-DC-022B.step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]
2020-10-28 refactor: more renaming
    [bigmuff.kicad_pcb, bigmuff.sch]
2021-01-07 refactor: a lot of renaming
    [fuzzpedal.kicad_pcb, fuzzpedal.sch]
2021-01-07 refactor: just a minor metadata fixes
    [fuzzpedal.sch]
2021-01-07 fix: increase hole size for the foot switch
    [fuzzpedal.kicad_pcb]
2021-01-07 fix: hole sizes of the jacks + bigger OSHW logo
    [fuzzpedal.kicad_pcb]
2021-01-07 add: kicad temp files to gitignore
2021-01-07 refactor: remove unused mechanical dir
    [1590B.stp]
2021-01-07 add: newly generated gerbers
    [bigmuff-B_Mask.gbr, bigmuff-B_SilkS.gbr, bigmuff-F_Mask.gbr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]
2021-01-07 add: hw revision version to 2.1
    [fuzzpedal.kicad_pcb, fuzzpedal.sch]
2021-02-06 add: better structure and description of assembly process
